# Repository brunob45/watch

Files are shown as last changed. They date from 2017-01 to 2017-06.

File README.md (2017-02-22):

# Main program for "analogic" numeric watch

 Code will work with my own design, available :
 https://oshpark.com/shared_projects/29Yy2Qri

 Microcontroller is an Atmel ATTiny88.
 http://www.atmel.com/images/doc8008.pdf
 
 Idea inspired from : 
 http://spikenzielabs.com/SpikenzieLabs/SolderTime.html

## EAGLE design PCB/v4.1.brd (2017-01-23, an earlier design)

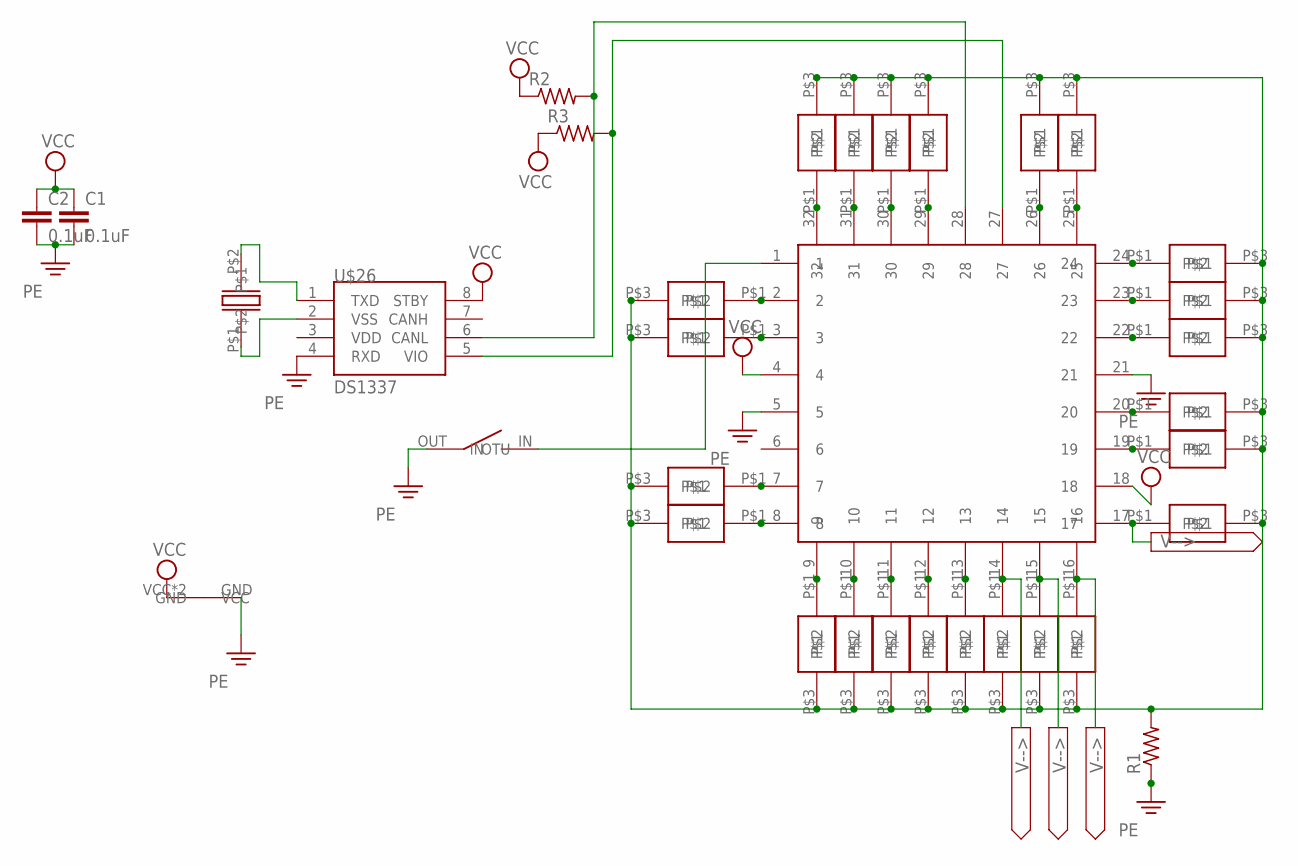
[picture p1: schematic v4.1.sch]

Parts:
C1, C2: 0.1uF; C0805K
R1, R2, R3: R-US_R0805; R0805
U$1, U$2, U$3, U$4, U$5, U$6, U$7, U$8, U$9, U$10, U$11, U$12, U$13, U$14, U$15, U$16, U$17, U$18, U$19, U$20, U$21, U$22, U$23, U$24: SMDLED
U$25: ATTINY88; 32-TQFT
U$26: DS1337; 8-SOIC
U$27: BAT2009
U$28: INT2
U$29: SMDCRYSTAL

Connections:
unnamed: U$16.P$1, U$25.2
unnamed: U$17.P$1, U$25.3
unnamed: U$7.P$1, U$25.7
unnamed: U$8.P$1, U$25.8
unnamed: U$18.P$1, U$25.9
unnamed: U$19.P$1, U$25.10
unnamed: U$20.P$1, U$25.11
unnamed: U$1.P$1, U$25.12
unnamed: U$2.P$1, U$25.13
unnamed: U$3.P$1, U$25.14
unnamed: U$11.P$1, U$25.17
unnamed: U$24.P$1, U$25.26
unnamed: U$9.P$1, U$25.25
unnamed: U$6.P$1, U$25.24
unnamed: U$22.P$1, U$25.23
unnamed: U$21.P$1, U$25.22
unnamed: U$25.1, U$28.IN
unnamed: U$10.P$1, U$25.20
unnamed: U$23.P$1, U$25.29
unnamed: U$13.P$1, U$25.30
unnamed: U$14.P$1, U$25.31
unnamed: U$15.P$1, U$25.32
unnamed: R1.2, U$1.P$3, U$2.P$3, U$3.P$3, U$4.P$3, U$5.P$3, U$6.P$3, U$7.P$3, U$8.P$3, U$9.P$3, U$10.P$3, U$11.P$3, U$12.P$3, U$13.P$3, U$14.P$3, U$15.P$3, U$16.P$3, U$17.P$3, U$18.P$3, U$19.P$3, U$20.P$3, U$21.P$3, U$22.P$3, U$23.P$3, U$24.P$3
unnamed: U$12.P$1, U$25.19
unnamed: U$26.2 (VSS), U$29.P$1
unnamed: U$26.1 (TXD), U$29.P$2
unnamed: U$5.P$1, U$25.16
unnamed: U$4.P$1, U$25.15
PE: C1.2, C2.2, R1.1, U$25.5, U$25.21, U$26.4 (RXD), U$27.GND, U$28.OUT (OTU)
SCL: R2.2, U$25.28, U$26.6 (CANL)
SDA: R3.2, U$25.27, U$26.5 (VIO)
VCC: C1.1, C2.1, R2.1, R3.1, U$25.4, U$25.18, U$26.8 (STBY), U$27.VCC, U$27.VCC2 (VCC)

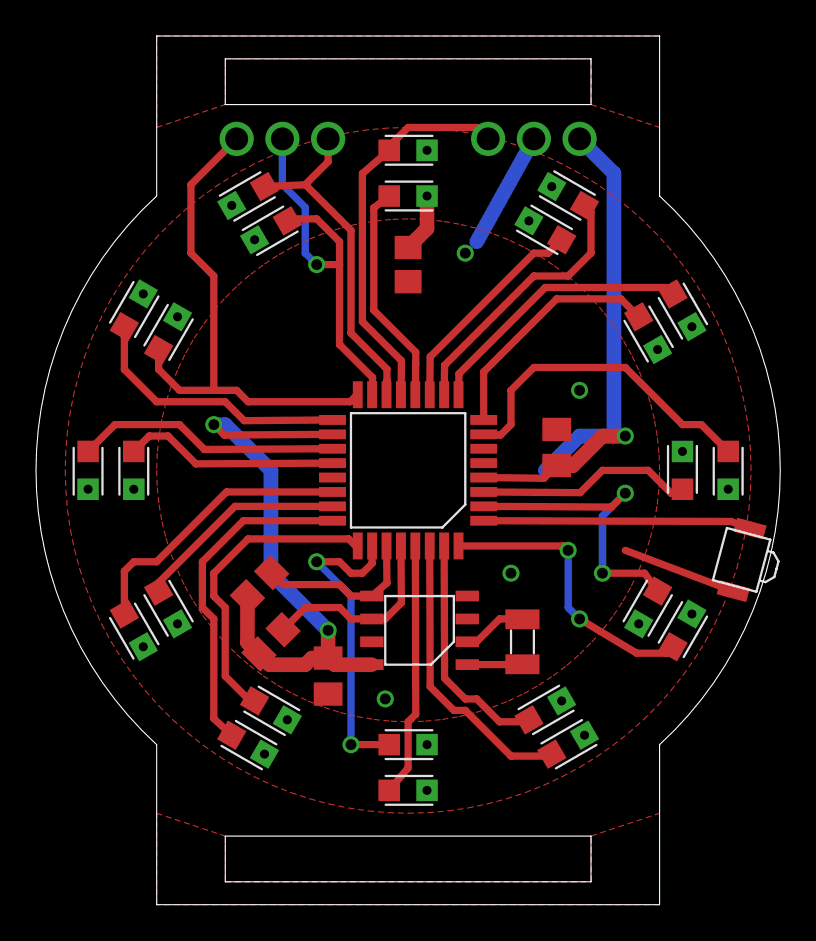
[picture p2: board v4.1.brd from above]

Board: 2 copper layers, 41.3 x 48.3 mm, 34 parts (1 on the bottom side), 32 nets.

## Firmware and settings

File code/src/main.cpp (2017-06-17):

/*
 * Nom: main.cpp
 * Copyright (C) 2016 Bruno Bousquet
 * License http://www.gnu.org/copyleft/gpl.html GNU/GPL
 * Description:
 * Version: 1.0
 * Date : 22 fev 2017
 */

#ifndef F_CPU
#warning "F_CPU not defined in <main.h>"
#define F_CPU 128000UL
#endif

#include <avr/io.h>
#include <avr/power.h>
#include <avr/sleep.h>
#include <avr/interrupt.h>

FUSES =
    {
        FUSE_SUT0,
        HFUSE_DEFAULT,
        EFUSE_DEFAULT,
};

#include "time.hpp"
#include "display.h"
#include "button.h"
#include "rtc.h"
#include "states.h"
#include "gpior.h"

static const uint8_t tick_index = 0;
static __inline__ void set_tick()
{
    GPIOReg::set(tick_index);
}
static __inline__ void clear_tick()
{
    GPIOReg::clear(tick_index);
}
static __inline__ void wait_tick()
{
    while (!GPIOReg::get(tick_index))
    {
        // wait
    }
}

ISR(TIMER0_COMPA_vect)
{
    set_tick();
}

ISR(INT1_vect)
{
    Button::DisableInterrupt();
}

int main()
{
    StateCtx::SetState(WakeUpState);

    uint8_t deb_cnt = 10;
    for (;;)
    {
        wait_tick();
        clear_tick();

        Button::get_current() ? Button::set_previous() : Button::clear_previous();

        deb_cnt--;
        if (deb_cnt == 0)
        {
            // do every 10 ms
            deb_cnt = 10;
            Button::Update();
        }

        StateCtx::Update();
        StateCtx::Perform();
    }
}

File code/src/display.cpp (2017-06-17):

/*
 * Nom: display.cpp
 * Copyright (C) 2016 Bruno Bousquet
 * License http://www.gnu.org/copyleft/gpl.html GNU/GPL
 * Description:
 * Version: 1.0
 * Date : 13 fev 2017
 */

#include <avr/io.h>
#include <avr/pgmspace.h>

#include "display.h"

// Workaround for http://gcc.gnu.org/bugzilla/show_bug.cgi?id=34734
#ifdef PROGMEM
#undef PROGMEM
#define PROGMEM __attribute__((section(".progmem.data")))
#endif

#define loc_of(x) (uint16_t)(&x)
#define data_of(x) (*(volatile uint8_t *)((uint16_t)x))

typedef struct
{
    uint8_t p;
    uint8_t b;
} led_t;

static struct
{
    led_t m;
    led_t h;
} current;

static led_t MEMDATA_H[] PROGMEM =
    {
        {loc_of(PORTD), _BV(0)},  // 0
        {loc_of(PORTC), _BV(2)},  // 1
        {loc_of(PORTC), _BV(0)},  // 2
        {loc_of(PORTC), _BV(7)},  // 3
        {loc_of(PORTB), _BV(5)},  // 4
        {loc_of(PORTB), _BV(3)},  // 5
        {loc_of(PORTB), _BV(0)},  // 6
        {loc_of(PORTD), _BV(7)},  // 7
        {loc_of(PORTB), _BV(7)},  // 8
        {loc_of(PORTA), _BV(3)},  // 9
        {loc_of(PORTD), _BV(4)},  // 10
        {loc_of(PORTD), _BV(1)}}; // 11

static led_t MEMDATA_M[] PROGMEM =
    {
        {loc_of(PORTC), _BV(3)},  // 0
        {loc_of(PORTC), _BV(1)},  // 1
        {loc_of(PORTA), _BV(1)},  // 2
        {loc_of(PORTA), _BV(0)},  // 3
        {loc_of(PORTB), _BV(4)},  // 4
        {loc_of(PORTB), _BV(2)},  // 5
        {loc_of(PORTB), _BV(1)},  // 6
        {loc_of(PORTD), _BV(6)},  // 7
        {loc_of(PORTD), _BV(5)},  // 8
        {loc_of(PORTB), _BV(6)},  // 9
        {loc_of(PORTA), _BV(2)},  // 10
        {loc_of(PORTD), _BV(2)}}; // 11

namespace Display
{

void init()
{
    DDRB = 0xFF;
    DDRC = 0x8F;
    DDRD = 0xF7;
    DDRA = 0x0F;
}

void showTime()
{
    for (uint8_t port = loc_of(PORTB); port <= loc_of(PORTA); port += 3)
    {
        uint8_t mask = 0;
        if (port == current.h.p)
        {
            mask |= current.h.b;
        }
        if (port == current.m.p)
        {
            mask |= current.m.b;
        }
        data_of(port) = mask;
    }

    set_show();
}

void setTime(Time t)
{
    uint16_t dw = pgm_read_word(&MEMDATA_H[t.h % 12]);
    current.h.b = (uint8_t)(dw >> 8);
    current.h.p = (uint8_t)(dw);

    dw = pgm_read_word(&MEMDATA_M[t.m / 5]);
    current.m.b = (uint8_t)(dw >> 8);
    current.m.p = (uint8_t)(dw);
}

void clear()
{
    PORTB = 0;
    PORTC = 0;
    PORTD = 0;
    PORTA = 0;

    clear_show();
}

void toggle()
{
    get_show() ? clear() : showTime();
}
}

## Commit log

2016-12-20 Add documentation
    [freq.xlsx]
2016-12-20 add timer namespaces and functions -- make them classes?
    [freq.xlsx]
2016-12-20 bug correction, add interrupt handler in Button, pin direction in LED, remove interrupt disable from interrupt handler
    [display.cpp, main.cpp]
2016-12-21 move src files to src directory
    [freq.xlsx]
2016-12-21 replace timer namespaces by static classes fix makefile
    [display.cpp, main.cpp]
2016-12-22 make button a class
2017-01-18 update Makefile to support fuse programmation
2017-01-19 add method for delay in ms for timers
2017-01-19 main now contains a test for the 12:00 led
    [freq.xlsx]
2017-01-23 Add PCB files to git
    [v4.0.brd, v4.0.sch, v4.1.brd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]
2017-02-14 Button making LEDs flashing and increment
2017-02-23 Fix setTime and clean code
    [display.cpp, main.cpp]
2017-04-26 final PCB sketch and fix time setting bug
    [main.cpp]
2017-04-26 Display : rename LED arrays
2017-04-26 added alias to set which LED ring is minutes and hours
2017-05-29 Using avr/power.h for power management
2017-06-17 Refactoring and power saving (#4)
    * Remove interrupts and apply state pattern
    * rename src folder to code, as it is used at another location
    * change RTC and TWI classes to namespaces
    * include vscode settings files
    * insert static code in TWI header
    * cleanup display showTime function
    * repo cleaning : remove unused files
    * Remove states from main and convert display to namespace
    * Remove redundant #include
    * Fix undefined macro
    * change current display array to struct
    * fix bitvalue mask mistake
    * add init and shutDown functions to Display
    * change tick static flag to a GPIOR flag (much faster)
    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
    [display.cpp, main.cpp]
2017-06-18 Tune timer to reflect real time better
